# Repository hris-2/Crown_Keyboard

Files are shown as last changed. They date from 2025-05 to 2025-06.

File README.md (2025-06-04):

# CROWN KEYBOARD
A simple 6 by 5 split keyboard with 3 thumb keys and a display.  
It is planned to be made through Ergogen, KiCad and ZMK.  
This not complete yet or fully tested so please do not use yet.  

## Features
As meationed before it is 6x5 with thumb keys all multiplied by 2 so 66 keys.  
It uses a Nice!Nano v2 so it has wireless and wired capability.  
Along with the Nice!Nano it has Nice!View for the display.  
The keyboard will include a reset button and a battery slider too.  
It will not be reverisble but can eaily bcome by removing mirrored sections and addin reversible tags to areas  

## Which Ergogen
I have been using https://ergogen.ceoloide.com the unoffical web version.  
Because it includes ability to add custom footprints there is no need for downloading it.  
For this reason all the inputs and outputs in the Ergogen folder aren't sorted like they would be on the local version.  
I would recommened this to people who are going for simpler designs.  
My footprints that I use are taken from Christian Selig.  

## Unusual Elements
Unlike most people I used outlines and combos for the mounting points intead of footprints in pcbs.  
I did this so i could visually see them in ergogen to stop the amount of times i had to switch between Ergogen and KiCad.  
It also has stilts for the pcb to sit on so i have room for the battery and maybe have foam or something to provide a bit more support. 

# THIS IS NOT FINISHED DO NOT USE YET PLEASE

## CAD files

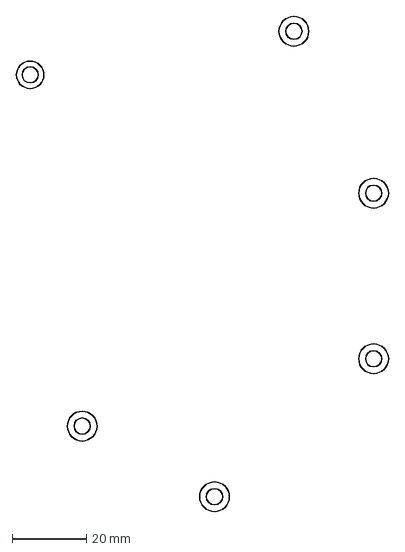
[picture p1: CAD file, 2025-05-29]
Ergogen/Outputs/left_stilts_w_holes.dxf
100.2 x 133.3 mm

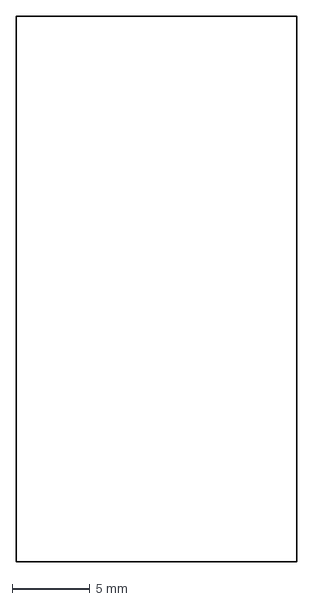
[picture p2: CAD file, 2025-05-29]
Ergogen/Outputs/Outlines/right_niceview_template.dxf
18.0 x 35.0 mm

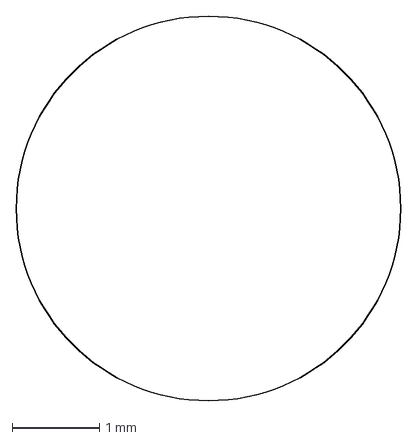
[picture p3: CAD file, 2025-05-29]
Ergogen/Outputs/Unimportant/right_mounting_hole-bottom_right.dxf
4.40 x 4.40 mm

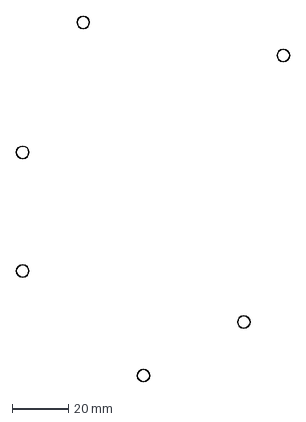
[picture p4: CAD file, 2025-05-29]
Ergogen/Outputs/Outlines/right_mounting_holes.dxf
96.9 x 129.7 mm

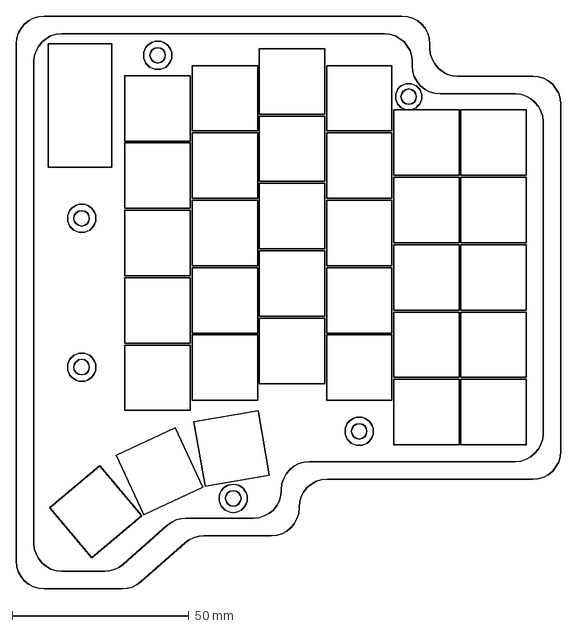
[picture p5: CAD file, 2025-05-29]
Ergogen/Outputs/right_combo.dxf
154.0 x 162.0 mm

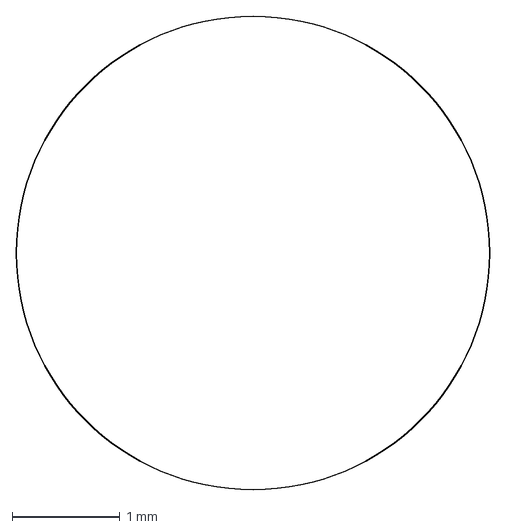
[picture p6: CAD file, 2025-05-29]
Ergogen/Outputs/Unimportant/right_mounting_hole-bottom_middle.dxf
4.40 x 4.40 mm

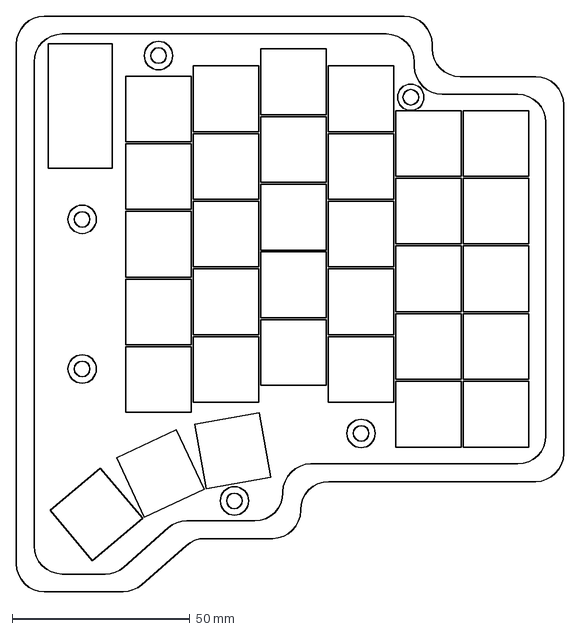
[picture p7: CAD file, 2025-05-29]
Ergogen/Outputs/Outlines/right_combo.dxf
154.0 x 162.0 mm

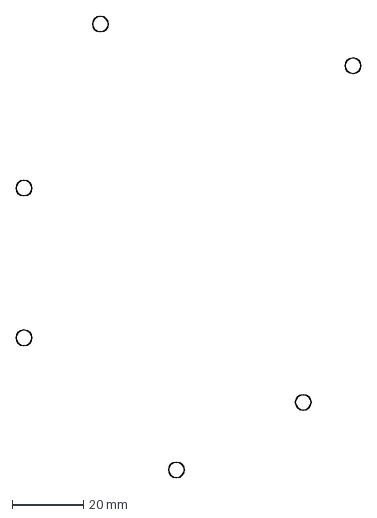
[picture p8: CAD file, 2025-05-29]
Ergogen/Outputs/right_mounting_holes.dxf
96.9 x 129.7 mm

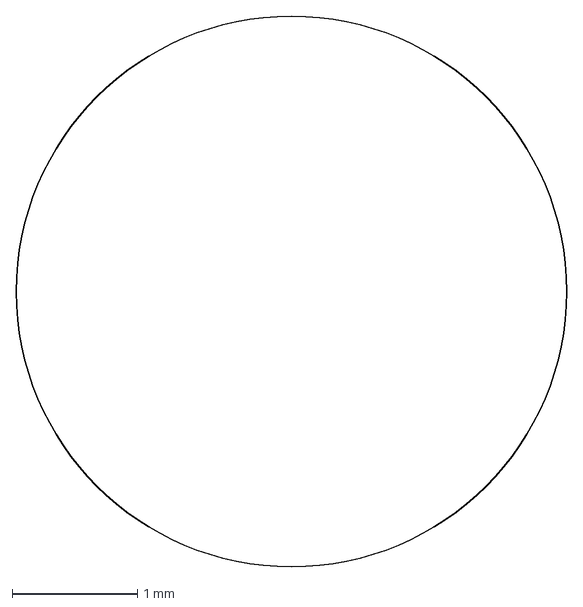
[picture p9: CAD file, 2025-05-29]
Ergogen/Outputs/Unimportant/left_mounting_hole-bottom_right.dxf
4.40 x 4.40 mm

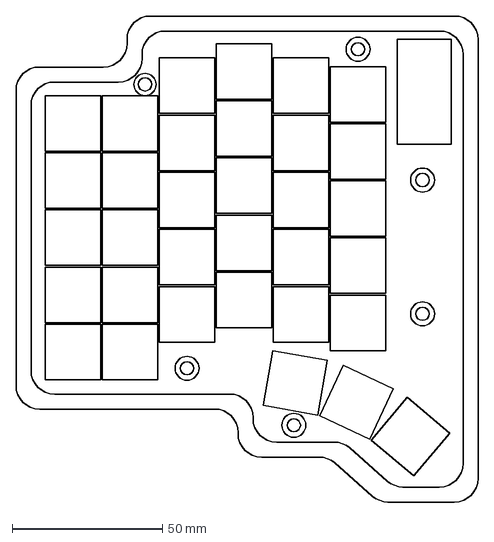
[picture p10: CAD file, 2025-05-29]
Ergogen/Outputs/left_combo.dxf
154.0 x 162.0 mm

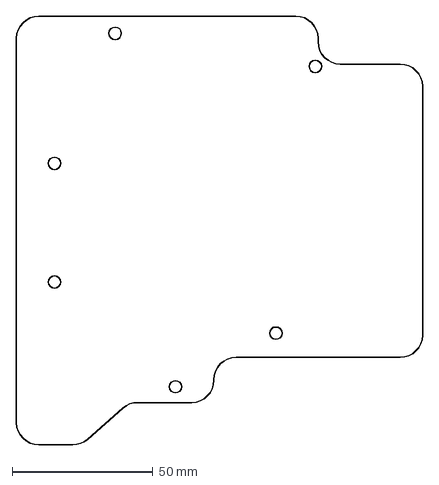
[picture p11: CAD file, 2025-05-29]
Ergogen/Outputs/Outlines/right_pcb.dxf
144.0 x 152.0 mm

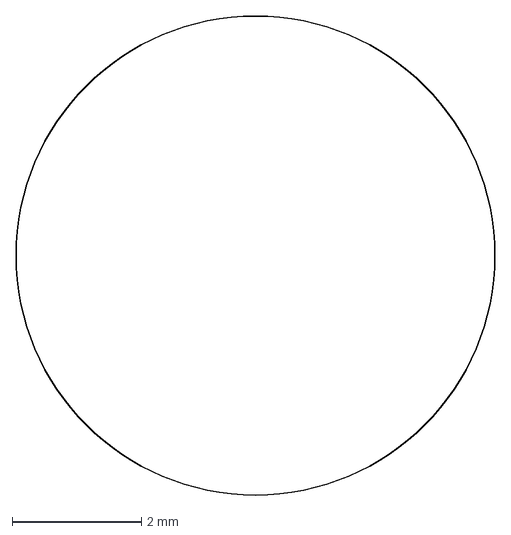
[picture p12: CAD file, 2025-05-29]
Ergogen/Outputs/Unimportant/right_stilts-top_left.dxf
7.40 x 7.40 mm

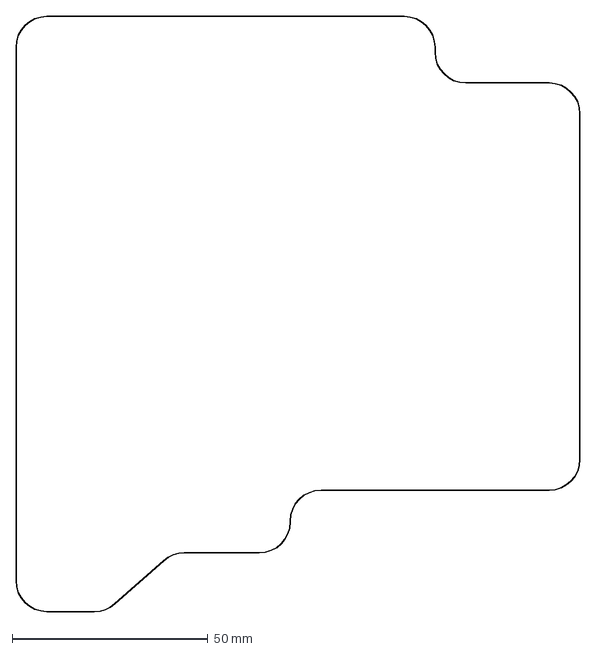
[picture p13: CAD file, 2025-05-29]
Ergogen/Outputs/Outlines/right_board.dxf
144.0 x 152.0 mm

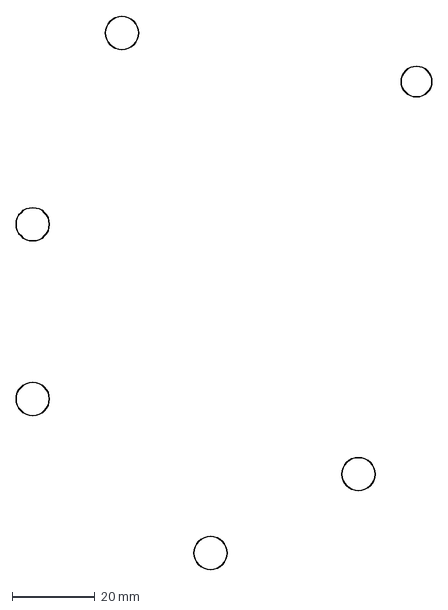
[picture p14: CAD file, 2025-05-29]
Ergogen/Outputs/right_stilts.dxf
100.2 x 133.3 mm

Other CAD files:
Ergogen/Outputs/Unimportant/right_stilts-top_middle.dxf
Ergogen/Outputs/left_stilts.dxf
Ergogen/Outputs/Outlines/left_xlboard.dxf
Ergogen/Outputs/Unimportant/right_mounting_hole-top_middle.dxf
Ergogen/Outputs/Outlines/both_combo.dxf
Ergogen/Outputs/Outlines/demo.dxf
Ergogen/Outputs/Outlines/keys_all.dxf
Ergogen/Outputs/Outlines/left_board.dxf
Ergogen/Outputs/Outlines/left_combo.dxf
Ergogen/Outputs/Outlines/left_keys.dxf
Ergogen/Outputs/Outlines/left_mounting_holes.dxf
Ergogen/Outputs/Outlines/left_niceview_template.dxf
Ergogen/Outputs/Outlines/left_pcb.dxf
Ergogen/Outputs/Outlines/left_stilts.dxf
Ergogen/Outputs/Outlines/left_stilts_w_holes.dxf
Ergogen/Outputs/Outlines/raw.dxf
Ergogen/Outputs/Outlines/right_keys.dxf
Ergogen/Outputs/Outlines/right_stilts.dxf
Ergogen/Outputs/Outlines/right_stlits_w_holes.dxf
Ergogen/Outputs/Outlines/right_xlboard.dxf
Ergogen/Outputs/Unimportant/demo.dxf
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

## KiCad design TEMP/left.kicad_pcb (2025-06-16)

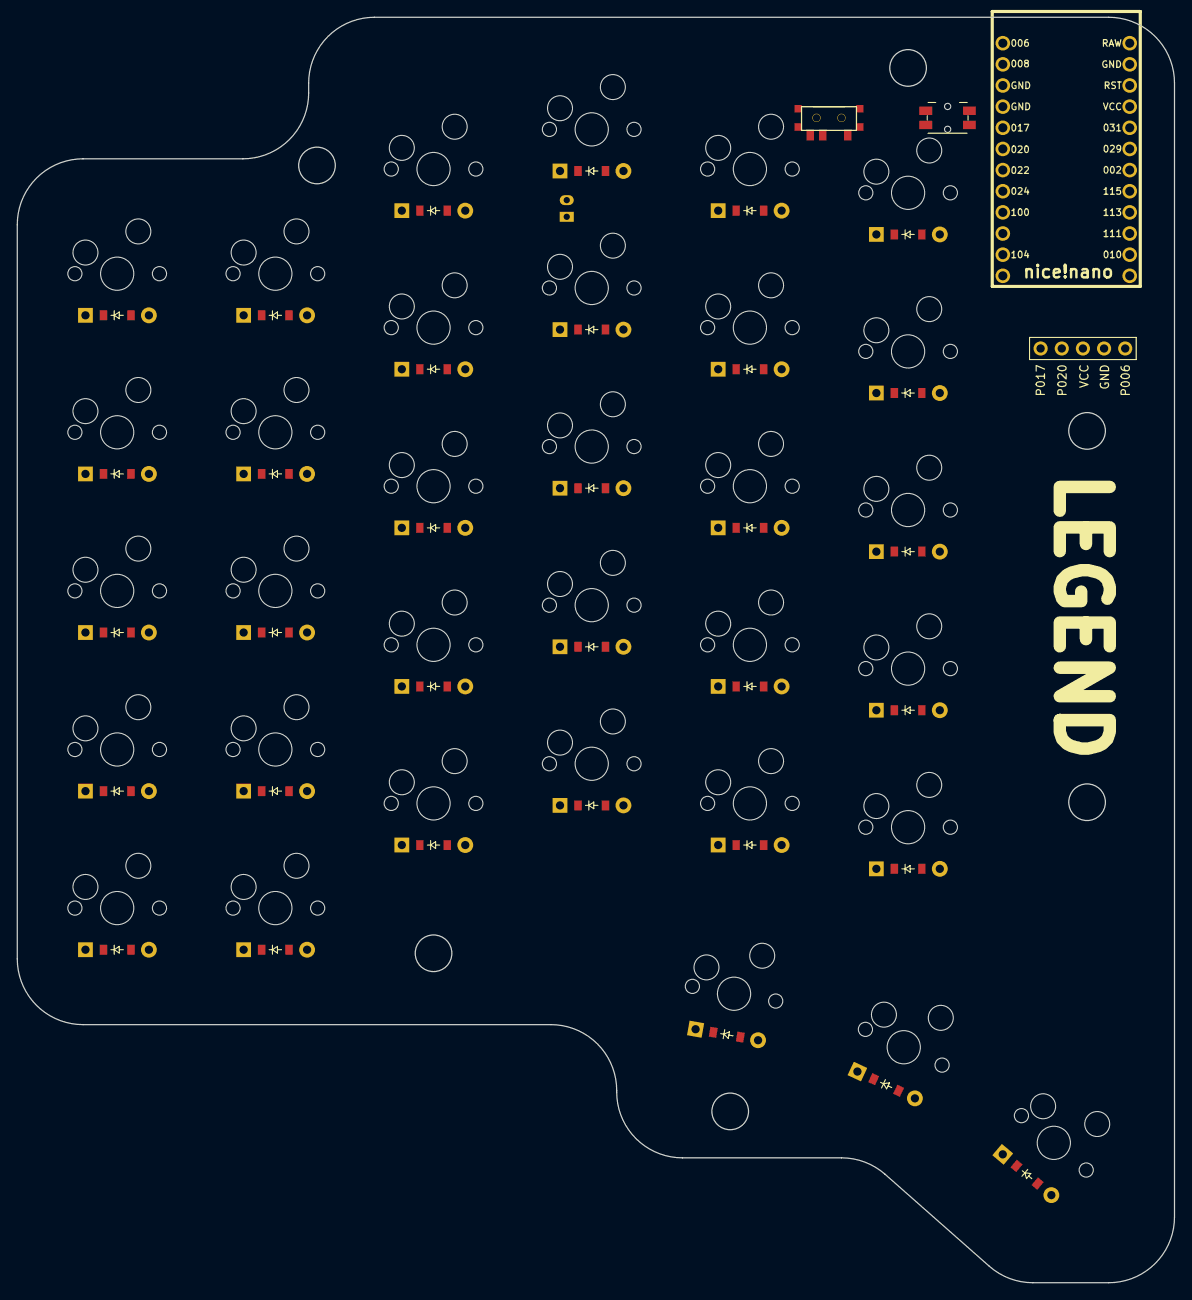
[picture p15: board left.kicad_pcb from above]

Board: 2 copper layers, 139.0 x 152.0 mm, 71 parts (0 on the bottom side), 53 nets, no tracks yet.

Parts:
B1: Panasonic_EVQPUL_EVQPUC
D1, D2, D3, D4, D5, D6, D7, D8, D9, D10, D11, D12, D13, D14, D15, D16, D17, D18, D19, D20, D21, D22, D23, D24, D25, D26, D27, D28, D29, D30, D31, D32, D33: ComboDiode
DISP1: display_nice_view
JST1: JST_PH_S2B-PH-K_02x2.00mm_Angled
MCU1: nice_nano
S1, S2, S3, S4, S5, S6, S7, S8, S9, S10, S11, S12, S13, S14, S15, S16, S17, S18, S19, S20, S21, S22, S23, S24, S25, S26, S27, S28, S29, S30, S31, S32, S33: MX
T1: SPDT_C128955

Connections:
GND: B1.1, DISP1.4, JST1.2, MCU1.3, MCU1.4, MCU1.23
P006: DISP1.5, MCU1.1
P017: DISP1.1, MCU1.5
P020: DISP1.2, MCU1.6
RAW: MCU1.24, T1.2
RST: B1.2, MCU1.22
VCC: DISP1.3, MCU1.21
col_1: MCU1.7, S26.1, S27.1, S28.1, S29.1, S30.1, S33.1
col_2: MCU1.8, S21.1, S22.1, S23.1, S24.1, S25.1, S32.1
col_3: MCU1.10, S16.1, S17.1, S18.1, S19.1, S20.1, S31.1
col_4: MCU1.9, S11.1, S12.1, S13.1, S14.1, S15.1
col_5: MCU1.11, S6.1, S7.1, S8.1, S9.1, S10.1
col_6: MCU1.12, S1.1, S2.1, S3.1, S4.1, S5.1
in_default: D31.2, S31.2
index_bottom: D22.2, S22.2
index_control: D21.2, S21.2
index_home: D23.2, S23.2
index_num: D25.2, S25.2
index_top: D24.2, S24.2
inner_bottom: D27.2, S27.2
inner_control: D26.2, S26.2
inner_home: D28.2, S28.2
inner_num: D30.2, S30.2
inner_top: D29.2, S29.2
mid_default: D32.2, S32.2
middle_bottom: D17.2, S17.2
middle_control: D16.2, S16.2
middle_home: D18.2, S18.2
middle_num: D20.2, S20.2
middle_top: D19.2, S19.2
out_default: D33.2, S33.2
outer_bottom: D2.2, S2.2
outer_control: D1.2, S1.2
outer_home: D3.2, S3.2
outer_num: D5.2, S5.2
outer_top: D4.2, S4.2
pinky_bottom: D7.2, S7.2
pinky_control: D6.2, S6.2
pinky_home: D8.2, S8.2
pinky_num: D10.2, S10.2
pinky_top: D9.2, S9.2
pos: JST1.1, T1.1
ring_bottom: D12.2, S12.2
ring_control: D11.2, S11.2
ring_home: D13.2, S13.2
ring_num: D15.2, S15.2
ring_top: D14.2, S14.2
row_1: D5.1, D10.1, D15.1, D20.1, D25.1, D30.1, MCU1.13
row_2: D4.1, D9.1, D14.1, D19.1, D24.1, D29.1, MCU1.14
row_3: D3.1, D8.1, D13.1, D18.1, D23.1, D28.1, MCU1.15
row_4: D2.1, D7.1, D12.1, D17.1, D22.1, D27.1, MCU1.16
row_5: D1.1, D6.1, D11.1, D16.1, D21.1, D26.1, MCU1.17
thumb_1: D31.1, D32.1, D33.1, MCU1.18

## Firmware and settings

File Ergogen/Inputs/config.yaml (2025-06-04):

units:
  kx: u
  ky: u
  px: kx + 2
  py: ky + 2
  dkx: kx + 8
  dky: ky + 8
points:
  zones:
    matrix:
      columns:
        outer:
          key:
            column_net: col_6
        pinky:
          key:
            column_net: col_5
        ring:
          key:
            stagger: 0.66U
            column_net: col_4
        middle:
          key:
            stagger: 0.25U
            column_net: col_3
        index:
          key:
            stagger: -0.25U
            column_net: col_2
        inner:
          key:
            stagger: -0.15U
            column_net: col_1
      rows:
        control:
          padding: U
          row_net: row_5
        bottom:
          padding: U
          row_net: row_4
        home:
          padding: U
          row_net: row_3
        top:
          padding: U 
          row_net: row_2
        num:
          padding: U 
          row_net: row_1
      anchor: 
        shift: [27,-120]
    thumb:
      anchor:
        ref: matrix_index_bottom
        shift: [-0.1U, -2.2U]
        rotate: -10
      columns:
        in:
          key:
            name: matrix_thumb_in 
            column_net: col_3
            row_net: thumb_1
        mid:
          key:
            spread: U
            splay: -15
            origin: [-0.5U, -0.5U]
            name: matrix_thumb_mid
            column_net: col_2
            row_net: thumb_1
        out:
          key:
            spread: U
            splay: -15
            origin: [-0.5U, -0.5U]
            column_net: col_1
            row_net: thumb_1         
            name: matrix_thumb_out
  mirror: &mirror
    ref: matrix_inner_num
    distance: 83
    resist: true  
outlines:
  raw:
    - what: rectangle
      where: true
      size: [px, py]
  keys_all:
    - what: rectangle
      where: true
      size: [kx-0.5,ky-0.5]
  left_keys:
    - what: rectangle
      where: /^matrix_.*/ 
      size: [kx-0.5,ky-0.5]
  right_keys:
    - what: rectangle
      where: /^mirror_.*/
      size: [kx-0.5,ky-0.5]
  left_board:
    - what: polygon
      operation: stack
      points:
        - ref: matrix_outer_control
          shift: [-14,-14]
        - ref: matrix_outer_control
          shift: [60,-14]
        - ref: matrix_outer_control
          shift: [60,-30]
        - ref: matrix_outer_control
          shift: [90,-30]
        - ref: matrix_outer_control
          shift: [107,-45]
        - ref: matrix_outer_control
          shift: [130,-45]
        - ref: matrix_outer_control
          shift: [130,107]
        - ref: matrix_outer_control
          shift: [23,107]
        - ref: matrix_outer_control 
          shift: [23,90]
        - ref: matrix_outer_control
          shift: [-14,90]
        - ref: matrix_outer_control
          shift: [-14,-14]
      fillet: 7.9
  right_board:
    - what: polygon
      operation: stack
      points:
        - ref: mirror_matrix_outer_control
          shift: [-14,-14]
        - ref: mirror_matrix_outer_control
          shift: [60,-14]
        - ref: mirror_matrix_outer_control
          shift: [60,-30]
        - ref: mirror_matrix_outer_control
          shift: [90,-30]
        - ref: mirror_matrix_outer_control
          shift: [107,-45]
        - ref: mirror_matrix_outer_control
          shift: [130,-45]
        - ref: mirror_matrix_outer_control
          shift: [130,107]
        - ref: mirror_matrix_outer_control
          shift: [23,107]
        - ref: mirror_matrix_outer_control 
          shift: [23,90]
        - ref: mirror_matrix_outer_control
          shift: [-14,90]
        - ref: mirror_matrix_outer_control
          shift: [-14,-14]
      fillet: 7.9
  left_xlboard:
    - what: polygon
      operation: stack
      points:
        - ref: matrix_outer_control
          shift: [-19,-19]
        - ref: matrix_outer_control
          shift: [55,-19]
        - ref: matrix_outer_control
          shift: [55,-35]
        - ref: matrix_outer_control
          shift: [85,-35]
        - ref: matrix_outer_control
          shift: [102,-50]
        - ref: matrix_outer_control
          shift: [135,-50]
        - ref: matrix_outer_control
          shift: [135,112]
        - ref: matrix_outer_control
          shift: [18,112]
        - ref: matrix_outer_control 
          shift: [18,95]
        - ref: matrix_outer_control
          shift: [-19,95]
        - ref: matrix_outer_control
          shift: [-19,-19]
      fillet: 7.9
  right_xlboard:
    - what: polygon
      operation: stack
      points:
        - ref: mirror_matrix_outer_control
          shift: [-19,-19]
        - ref: mirror_matrix_outer_control
          shift: [55,-19]
        - ref: mirror_matrix_outer_control
          shift: [55,-35]
        - ref: mirror_matrix_outer_control
          shift: [85,-35]
        - ref: mirror_matrix_outer_control
          shift: [102,-50]
        - ref: mirror_matrix_outer_control
          shift: [135,-50]
        - ref: mirror_matrix_outer_control
          shift: [135,112]
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

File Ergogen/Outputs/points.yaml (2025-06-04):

matrix_outer_control:
  x: 27
  'y': -120
  r: 0
  meta:
    stagger: 0
    spread: 19
    splay: 0
    origin:
      - 0
      - 0
    orient: 0
    shift:
      - 0
      - 0
    rotate: 0
    adjust: {}
    width: 18
    height: 18
    padding: 19.05
    autobind: 10
    skip: false
    asym: both
    colrow: outer_control
    name: matrix_outer_control
    column_net: col_6
    row_net: row_5
    zone: &ref_1
      columns:
        outer: &ref_0
          key:
            column_net: col_6
          rows: {}
          name: outer
        pinky: &ref_2
          key:
            column_net: col_5
          rows: {}
          name: pinky
        ring: &ref_3
          key:
            stagger: 0.66U
            column_net: col_4
          rows: {}
          name: ring
        middle: &ref_4
          key:
            stagger: 0.25U
            column_net: col_3
          rows: {}
          name: middle
        index: &ref_5
          key:
            stagger: '-0.25U'
            column_net: col_2
          rows: {}
          name: index
        inner: &ref_6
          key:
            stagger: '-0.15U'
            column_net: col_1
          rows: {}
          name: inner
      rows:
        control:
          padding: U
          row_net: row_5
        bottom:
          padding: U
          row_net: row_4
        home:
          padding: U
          row_net: row_3
        top:
          padding: U
          row_net: row_2
        num:
          padding: U
          row_net: row_1
      name: matrix
    col: *ref_0
    row: control
    mirrored: false
    bind:
      - 10
      - 10
      - 0
      - 0
matrix_outer_bottom:
  x: 27
  'y': -100.95
  r: 0
  meta:
    stagger: 0
    spread: 19
    splay: 0
    origin:
      - 0
      - 0
    orient: 0
    shift:
      - 0
      - 0
    rotate: 0
    adjust: {}
    width: 18
    height: 18
    padding: 19.05
    autobind: 10
    skip: false
    asym: both
    colrow: outer_bottom
    name: matrix_outer_bottom
    column_net: col_6
    row_net: row_4
    zone: *ref_1
    col: *ref_0
    row: bottom
    mirrored: false
    bind:
      - 10
      - 10
      - 10
      - 0
matrix_outer_home:
  x: 27
  'y': -81.9
  r: 0
  meta:
    stagger: 0
    spread: 19
    splay: 0
    origin:
      - 0
      - 0
    orient: 0
    shift:
      - 0
      - 0
    rotate: 0
    adjust: {}
    width: 18
    height: 18
    padding: 19.05
    autobind: 10
    skip: false
    asym: both
    colrow: outer_home
    name: matrix_outer_home
    column_net: col_6
    row_net: row_3
    zone: *ref_1
    col: *ref_0
    row: home
    mirrored: false
    bind:
      - 10
      - 10
      - 10
      - 0
matrix_outer_top:
  x: 27
  'y': -62.85000000000001
  r: 0
  meta:
    stagger: 0
    spread: 19
    splay: 0
    origin:
      - 0
      - 0
    orient: 0
    shift:
      - 0
      - 0
    rotate: 0
    adjust: {}
    width: 18
    height: 18
    padding: 19.05
    autobind: 10
    skip: false
    asym: both
    colrow: outer_top
    name: matrix_outer_top
    column_net: col_6
    row_net: row_2
    zone: *ref_1
    col: *ref_0
    row: top
    mirrored: false
    bind:
      - 10
      - 10
      - 10
      - 0
matrix_outer_num:
  x: 27
  'y': -43.80000000000001
  r: 0
  meta:
    stagger: 0
    spread: 19
    splay: 0
    origin:
      - 0
      - 0
    orient: 0
    shift:
      - 0
      - 0
    rotate: 0
    adjust: {}
    width: 18
    height: 18
    padding: 19.05
    autobind: 10
    skip: false
    asym: both
    colrow: outer_num
    name: matrix_outer_num
    column_net: col_6
    row_net: row_1
    zone: *ref_1
    col: *ref_0
    row: num
    mirrored: false
    bind:
      - 0
      - 10
      - 10
      - 0
matrix_pinky_control:
  x: 46
  'y': -120
  r: 0
  meta:
    stagger: 0
    spread: 19
    splay: 0
    origin:
      - 0
      - 0
    orient: 0
    shift:
      - 0
      - 0
    rotate: 0
    adjust: {}
    width: 18
    height: 18
    padding: 19.05
    autobind: 10
    skip: false
    asym: both
    colrow: pinky_control
    name: matrix_pinky_control
    column_net: col_5
    row_net: row_5
    zone: *ref_1
    col: *ref_2
    row: control
    mirrored: false
    bind:
      - 10
      - 0
      - 0
      - 10
matrix_pinky_bottom:
  x: 46
  'y': -100.95
  r: 0
  meta:
    stagger: 0
    spread: 19
    splay: 0
    origin:
      - 0
      - 0
    orient: 0
    shift:
      - 0
      - 0
    rotate: 0
    adjust: {}
    width: 18
    height: 18
    padding: 19.05
    autobind: 10
    skip: false
    asym: both
    colrow: pinky_bottom
    name: matrix_pinky_bottom
    column_net: col_5
    row_net: row_4
    zone: *ref_1
    col: *ref_2
    row: bottom
    mirrored: false
    bind:
      - 10
      - 10
      - 10
      - 10
matrix_pinky_home:
  x: 46
  'y': -81.9
  r: 0
  meta:
    stagger: 0
    spread: 19
    splay: 0
    origin:
      - 0
      - 0
    orient: 0
    shift:
      - 0
      - 0
    rotate: 0
    adjust: {}
    width: 18
    height: 18
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

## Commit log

2025-05-28 Create TEMP to Create KiCad
2025-05-28 Create TEMP to Create PCB.KiCad
2025-05-28 Create TEMP to Create Gerber
2025-05-28 Create TEMP to Create Footprints
2025-05-28 Create TEMP to Create Footprints to Correct Mistake
2025-05-28 Move left.kicad_pcb to Ergogen/Outputs/left.kicad_pcb
    [left.kicad_pcb]
2025-05-28 Move right.kicad_pcb to Ergogen/Outputs/right.kicad_pcb
    [right.kicad_pcb]
2025-05-28 Create TEMP to Create Footprints to Correct Mistakes
2025-05-29 Move demo.dfx Ergogen/Outputs/Unimportant to Ergogen/Outputs
    [demo.dxf]
2025-05-29 Create TEMP to Create Case & KeyCaps
2025-06-04 Update config.yaml with minor changes and fixes
    [config.yaml]
2025-06-04 Add raw.txt adn right and left .kicad_pcb files to match changes in config.yaml
    [left.kicad_pcb, right.kicad_pcb]
2025-06-05 Add "h_ris" to Company Section in left.kicad_pcb
    [left.kicad_pcb]
2025-06-05 Add "h_ris" to Company Section in right.kicad_pcb
    [right.kicad_pcb]
